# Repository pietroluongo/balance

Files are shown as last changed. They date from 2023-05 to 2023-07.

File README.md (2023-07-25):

# Mesa Balanceadora

### Autores: Gabriel Pietroluongo Nascimento, Luiz Gabriel Bandeira e Ribeiro, Otávio Costa Sales

O projeto consiste em um sistema de reconhecimento de imagem e uma mesa acoplada a servo motores. O sistema é capaz de identificar a posição de um objeto (no nosso exemplo, uma bolinha de pingue-pongue laranja) pela cor e movimentar a mesa utilizando os servos para que o objeto não caia da mesa. O projeto foi desenvolvido na disciplina de Projeto Integrado de Computação II, ofertada na Universidade Federal do Espírito Santo.

## Arquitetura


Existem ao todo quatro componentes no sistema, dois principais (a ESP e o Computador) e dois secundários (a câmera e os servos).
A câmera serve para fornecer de forma contínua a posição do objeto. Ele envia as imagens (os frames do video) para o computador.
O computador é responsável por receber cada frame do vídeo, identificar todos os pixels da cor selecionada e enviar a média desses pixels para a ESP-32, num formato JSON {x, y}
A ESP cuida do controle PID, responsável por calcular como os servo motores precisam atuar para que o objeto se mantenha equilibrado em cima da mesa.
Os servo motores são responsáveis por movimentar a mesa, fazendo com o que o objeto raramente escorregue para fora.

## Como executar
As informações específicas sobre como rodar cada um dos dois módulos estão disponíveis nas subpastas específicas de cada módulo.
- [ESP](https://github.com/pietroluongo/balance/tree/main/esp)
- [Câmera](https://github.com/pietroluongo/balance/tree/main/camera)

Além disso, os arquivos `.blend` esão disponíveis na pasta [PIC2](https://github.com/pietroluongo/balance/tree/main/PIC2)

# Requisitos
## Requisitos de software
- [DroidCam](https://play.google.com/store/apps/details?id=com.dev47apps.droidcam&hl=en&gl=US) para captar as imagens através do celular e enviá-las para uma rede local
- Python 3 e OpenCV para o código do reconhecimento de imagem
- MQTT para o envio de informações entre o notebook e a ESP
- C++, PlataformIO para o código de controle PID
- Blender para criar os modelos 3d necessários
## Requisitos de hardware
- Câmera
- Um computador para rodar o código de reconhecimento de imagem.
- Um microcontrolador para rodar o código de controle PID.
- Dois servo motores
## Hardware utilizado
- Celular com câmera
- Notebook para rodar o código de reconhecimento de imagem.
- Microcontrolador ESP-32 para controle dos motores
- Servo motor SG-90 (x2)
## Outros requisitos
- Peças impressas em 3D
- Material em MDF para construção da estrutura da mesa
- [Junta Universal 1/4"](https://www.amazon.com.br/Stanley-4-86-011-Junta-Universal-Amarelo/dp/B076VQ5KH9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)

## Mais mídias


Peças impressas em impressora 3D para suporte dos servo motores e da mesa


Imagem de referência de como ficou a montagem



Modelo 3D do servo motor utilizado para a montagem do suporte



Primeiro protótipo funcional

[Video da mesa em ação](https://www.youtube.com/shorts/Di8BZghZs8M)

# Referências
Vídeos no Youtube:
- [Ball Balancing PID System](https://www.youtube.com/watch?v=7Jw8m4pbTYI&t=2s)
- [PID Balance+Ball | full explanation & tuning](https://www.youtube.com/watch?v=JFTJ2SS4xyA)
- [Acrome Ball Balancing Table](https://www.youtube.com/watch?v=tPr6-Rh0m-8)

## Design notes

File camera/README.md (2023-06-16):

# balance - Camera module

## How to run

Assuming you have conda installed, run

```conda create --name <environment_name> --file requirements.txt```

To create a new env with the required dependencies, or

```conda install --file requirements.txt```

If you already have the dependencies installed.

Update the line

```self._cap = cv2.VideoCapture("http://192.168.0.101:4747/video")```

On camera.py to use your own ip address, or to '0' instead of an ip address to use a webcam.

---
## Notes

Prefer running on a 1080p screen for a better HUD layout.

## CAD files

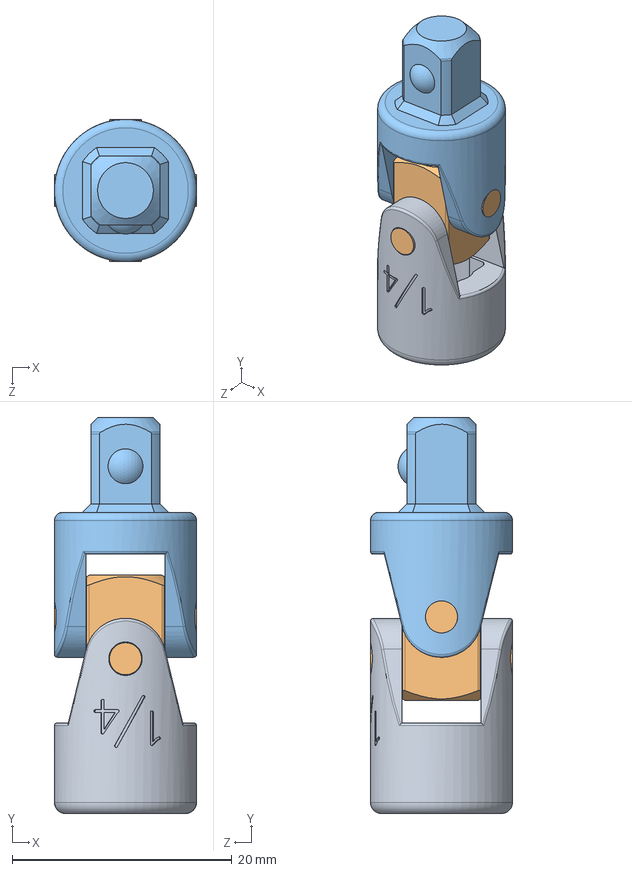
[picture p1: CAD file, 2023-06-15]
PIC2/joint/Craftsman Socket U-Joint_4280.step
13.0 x 36.1 x 13.0 mm
Craftsman Socket U-Joint Base_4280
Craftsman Socket U-Joint Intermediate Body_4280
Craftsman Socket U-Joint Drive_4280-Drive

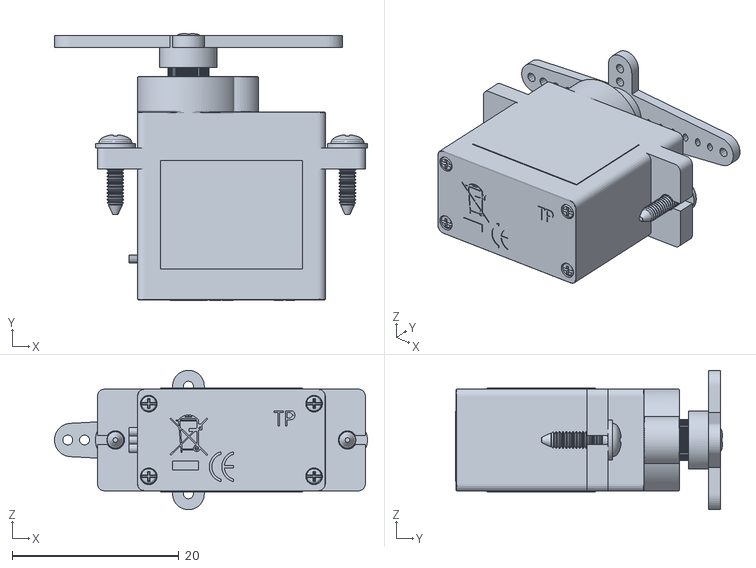
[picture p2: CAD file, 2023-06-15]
PIC2/servo/ImageToStl.com_sg90 - micro servo 9g - tower pro.obj
37.5 x 32.0 x 16.7

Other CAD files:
PIC2/joint/joint.obj
PIC2/joint/joint.blend

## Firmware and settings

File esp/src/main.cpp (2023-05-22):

#include <Arduino.h>
#include <ArduinoJson.h>
#include <PubSubClient.h>
#include <Servo.h>
#include <wifiStuff.h>

// #include <ESP8266WiFi.h>
#include <WiFi.h>
#include <string>

const bool SHOULD_PRINT = false;

Servo servo;
Servo servo2;

#define SERVO_PIN 14   // GPIO13
#define SERVO_2_PIN 26 // GPIO14

WiFiClient espClient;
PubSubClient client(espClient);

StaticJsonDocument<1024> doc;

int m1 = 0;
int m2 = 0;

void callback(char *topic, byte *message, unsigned int length) {
  if (SHOULD_PRINT) {
    Serial.println("Callback");
    Serial.print("Message arrived on topic: ");
    Serial.print(topic);
    Serial.print(". Message: ");
  }
  char json[1024];
  for (unsigned int i = 0; i < length; i++) {
    if (SHOULD_PRINT) {
      Serial.print((char)message[i]);
    }
    json[i] = (char)message[i];
  }
  // Serial.println();
  DeserializationError error = deserializeJson(doc, json);
  if (error) {
    Serial.print(F("deserializeJson() failed: "));
    Serial.println(error.f_str());
    return;
  }
  // global_pos = doc["pos"];
  // Serial.printf("%d\n", global_pos);
  m1 = doc["m1"];
  m2 = doc["m2"];
  // Serial.printf("Got following coordinates: %d\n", global_pos);
  // Serial.printf("Got following data: (m1, m2) = (%d, %d)\n", m1, m2);
}

void setup() {
  Serial.begin(115200);

  pinMode(SERVO_PIN, OUTPUT);
  pinMode(SERVO_2_PIN, OUTPUT);

  servo.attach(SERVO_PIN);
  servo.write(0);

  servo2.attach(SERVO_2_PIN);
  servo2.write(0);
  setup_wifi(client);
  client.setCallback(callback);
}

void loop() {
  if (!client.connected()) {
    reconnect(client);
  }
  client.loop();
  servo.write(m1);
  servo2.write(m2);
  // for (int pos = 0; pos <= 180;
  //      pos += 1) { // goes from 0 degrees to 180 degrees
  //   // in steps of 1 degree
  //   servo.write(pos);        // tell servo to go to position in variable
  //   'pos' servo2.write(180 - pos); // tell servo to go to position in
  //   variable 'pos' delay(15);               // waits 15ms for the servo to
  //   reach the position
  // }
  // for (int pos = 180; pos >= 0;
  //      pos -= 1) {           // goes from 180 degrees to 0 degrees
  //   servo.write(pos);        // tell servo to go to position in variable
  //   'pos' servo2.write(180 - pos); // tell servo to go to position in
  //   variable 'pos' delay(15);               // waits 15ms for the servo to
  //   reach the position
  // }
  // for (int i = 0; i < 3; i++) {
  //   delay(200);
  //   Serial.printf("writing %d\n", i * 90);
  //   servo.write(90 * i);
  //   servo2.write(90 * i);
  // }
  // servo.write(45);
  // delay(500);
  // servo.write(135);
  // delay(500);
}

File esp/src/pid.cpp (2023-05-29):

#include <Arduino.h>
#include <ArduinoJson.h>
#include <PubSubClient.h>
#include <Servo.h>
#include <wifiStuff.h>

#include <WiFi.h>
#include <cstring>
#include <string>

Servo servo;
Servo servo2;

#define SERVO_PIN 14   // GPIO13
#define SERVO_2_PIN 26 // GPIO14

WiFiClient espClient;
PubSubClient client(espClient);

StaticJsonDocument<1024> doc;

int posX, posY = 0;

struct PID {
  float kp;
  float ki;
  float kd;
};

PID pid_m0 = {0};
PID pid_m1 = {0};

const int targetX = 329;
const int targetY = 227;

void updatePIDStuff();

void callback(char *topic, byte *message, unsigned int length) {
  char json[1024];
  for (unsigned int i = 0; i < length; i++) {
    json[i] = (char)message[i];
  }
  DeserializationError error = deserializeJson(doc, json);
  if (error) {
    Serial.print(F("deserializeJson() failed: "));
    Serial.println(error.f_str());
    return;
  }
  if (strcmp(topic, "/balance/m0/pid") == 0) {
    pid_m0.kp = doc["p"];
    pid_m0.ki = doc["i"];
    pid_m0.kd = doc["d"];
    Serial.printf("Got following M0 PID values: (%f, %f, %f)\n", pid_m0.kp,
                  pid_m0.ki, pid_m0.kd);
  } else if (strcmp(topic, "/balance/m1/pid") == 0) {
    pid_m1.kp = doc["p"];
    pid_m1.ki = doc["i"];
    pid_m1.kd = doc["d"];
    Serial.printf("Got following M1 PID values: (%f, %f, %f)\n", pid_m1.kp,
                  pid_m1.ki, pid_m1.kd);
  }

  if (strcmp(topic, "/balance/ball") == 0) {
    posX = doc["x"];
    posY = doc["y"];
    updatePIDStuff();
  }
}

int lastDeltaY = 0;
int lastDeltaX = 0;

void updatePIDStuff() {
  int p = targetY - posY;
  int d = p - lastDeltaY;
  lastDeltaY = p;
  int output = -(p * pid_m0.kp + d * pid_m0.kd) / 0.44;
  servo.write(90 + output);

  p = targetX - posX;
  d = p - lastDeltaX;
  lastDeltaX = p;
  output = -(p * pid_m1.kp + d * pid_m1.kd) / 0.44;
  Serial.printf("Output: %d\n", output);
  servo2.write(90 + output);
}

void setup() {
  Serial.begin(115200);

  pinMode(SERVO_PIN, OUTPUT);
  pinMode(SERVO_2_PIN, OUTPUT);

  servo.attach(SERVO_2_PIN);
  servo.write(90);

  servo2.attach(SERVO_PIN);
  servo2.write(90);

  setup_wifi(client);
  client.setCallback(callback);
}

void loop() {
  if (!client.connected()) {
    reconnect(client);
  }
  client.loop();
}

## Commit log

2023-04-06 improving color picker and board detection
2023-05-22 Moved camera-related code to camera folder
2023-05-25 Updated PID control layout
2023-05-29 General improvements to camera code
2023-06-15 Added PIC2 3D model
    [Craftsman Socket U-Joint_4280.step, ImageToStl.com_sg90 - micro servo 9g - tower pro.obj, joint.blend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]
2023-06-21 updating joint holes
2023-07-10 Added camera requirements
